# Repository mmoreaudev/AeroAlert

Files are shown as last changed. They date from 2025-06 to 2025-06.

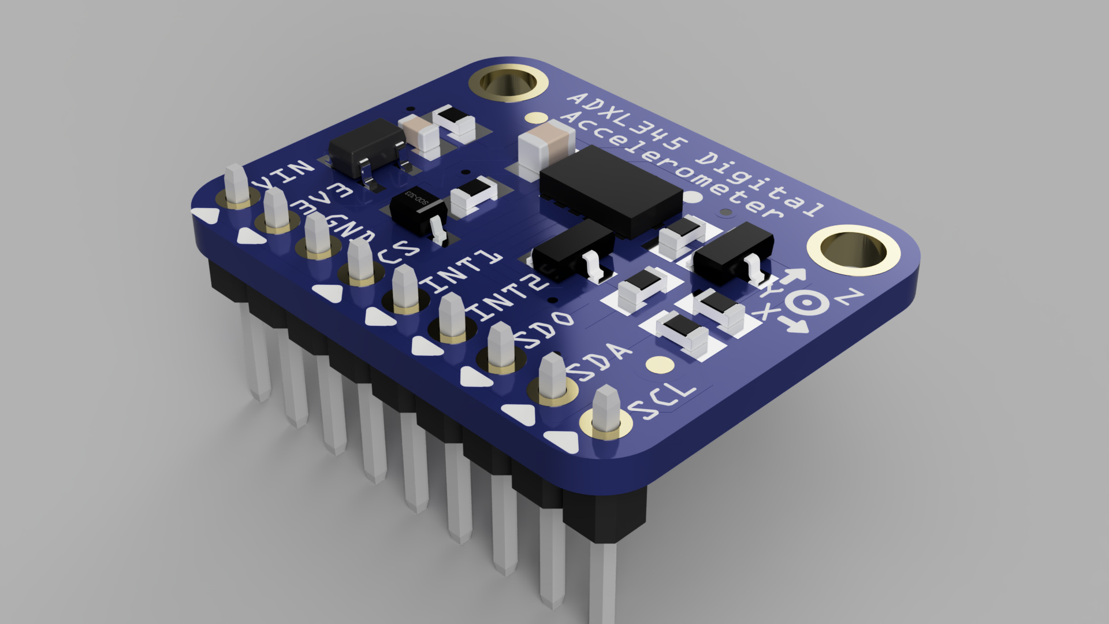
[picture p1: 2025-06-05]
Carte PCB/adxl345-digital-accelerometer-adafuit-breakout-board-1.snapshot.1/Render 2.jpg

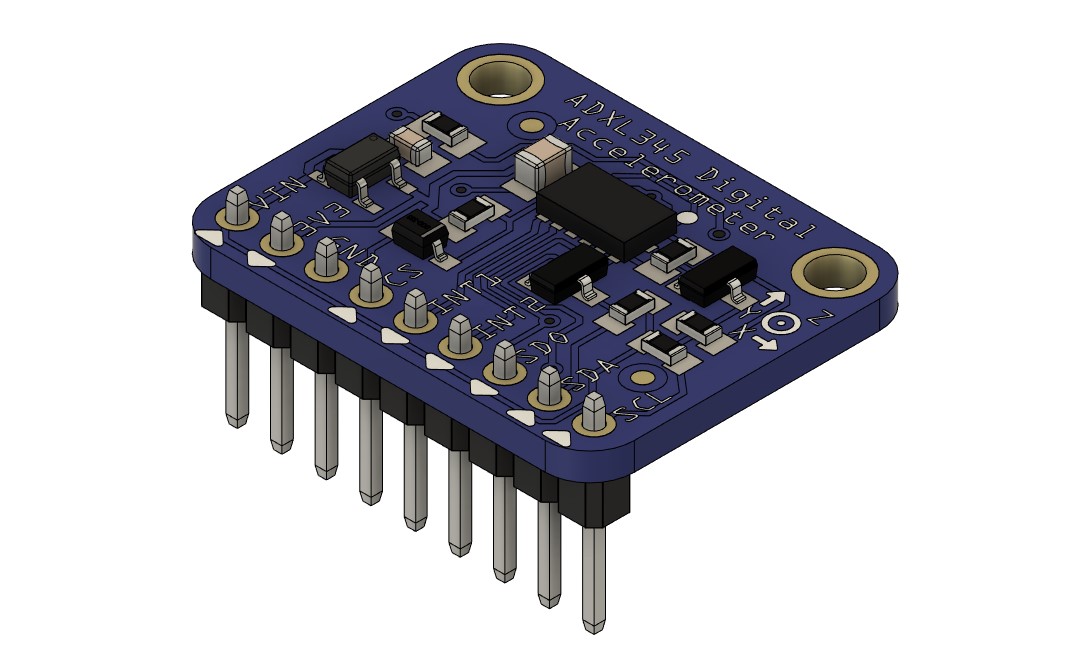
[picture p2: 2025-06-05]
Carte PCB/adxl345-digital-accelerometer-adafuit-breakout-board-1.snapshot.1/ADXL345 Digital Accelerometer.jpg

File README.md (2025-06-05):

# 🌤️ AeroAlert

**AeroAlert** is a lightweight, reusable, and cost-effective meteorological probe system designed to study **meteorological epiphenomena** using miniaturized sensors deployed via rockets. Our goal is to improve understanding and forecasting of high-risk weather events by collecting simultaneous atmospheric data across multiple points within a small geographical area.

---

## 🚀 Project Overview

The AeroAlert system works as follows:

1. **Launch**: A compact rocket is launched into the atmosphere.
2. **Deployment**: Upon reaching maximum altitude, a parachute is deployed.
3. **Data Collection**: While descending, the onboard sensors collect meteorological data.
4. **Storage & Visualization**: Collected data is stored and later visualized using a dedicated Human-Machine Interface (HMI).

---

## 🎯 Purpose

The core objective of AeroAlert is to **study meteorological epiphenomena**—those rare or secondary weather-related events that are often difficult to capture using conventional equipment. By deploying multiple inexpensive probes simultaneously across a small region, we can:

- Collect high-resolution atmospheric data
- Analyze localized phenomena
- Improve early detection and forecasting of extreme weather conditions

---

## 🧰 Technologies Used

- 🛰️ **Embedded sensors** for atmospheric data (e.g., temperature, humidity, pressure)
- 💻 **Microcontroller (e.g., Arduino, ESP32)** for data acquisition and storage
- 🪂 **Mechanical parachute deployment system**
- 📈 **HMI (Human-Machine Interface)** for data visualization
- 🚀 **Model rocket system** for deployment
- 🔋 **Battery-powered modules** for portability and reusability

---

## 🛠️ Installation & Setup

> *Note: Hardware setup and code repository coming soon*

### Prerequisites

- Microcontroller development environment (e.g., MICROCHIP)
- Sensor modules (temperature, pressure, humidity, etc.)
- Model rocket and deployment hardware
- Local or web-based interface for HMI

### Clone the Repository

```bash
git clone https://github.com/your-username/aeroalert.git
cd aeroalert
```

## 📊 Data & Visualization
All collected meteorological data (such as temperature, pressure, and humidity at various altitudes) is stored in onboard memory and can be exported in CSV/JSON format. The HMI displays this data through:

- Interactive graphs 📉
- Real-time metrics 📡
- Historical logs 🗂️
- ♻️ Reusability & Portability

## AeroAlert is designed with:

- 🔋 Long battery life
- 🪶 Lightweight components
- 🔄 Modular structure for easy reconfiguration and redeployment
- 🤝 Contributing

Contributions are welcome! Feel free to fork the repository and submit a pull request. Whether you're into electronics, data science, or rocket science — we’d love your help! 🛠️

1. Fork the project
2. Create your feature branch (git checkout -b feature/AmazingFeature)
3. Commit your changes (git commit -m 'Add some AmazingFeature')
4. Push to the branch (git push origin feature/AmazingFeature)
5. Open a Pull Request

### 📄 License
This project is licensed under the MIT License.

See the LICENSE file for more details.

## 🌐 Acknowledgments
Translations by DeepL
Open-source community for sensor integration support
Educators and meteorologists providing guidance on atmospheric studies

### AeroAlert – Because understanding the sky helps us protect the Earth. ☁️🌎

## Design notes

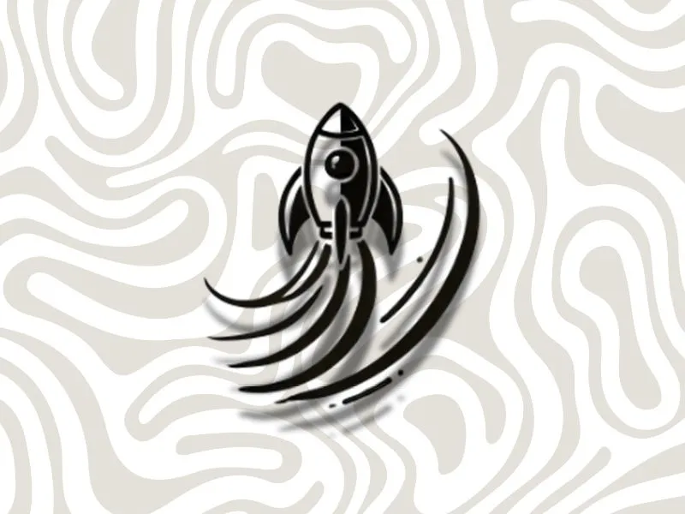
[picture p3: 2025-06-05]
Baniere.webp

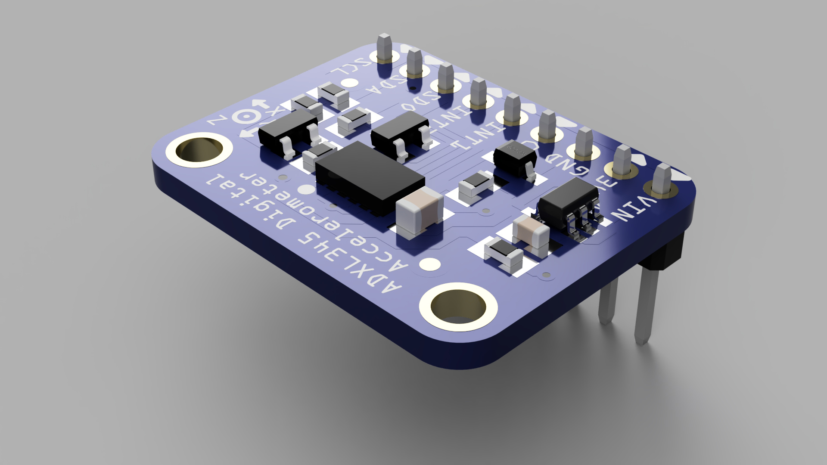
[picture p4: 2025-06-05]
Carte PCB/adxl345-digital-accelerometer-adafuit-breakout-board-1.snapshot.1/Render 1.jpg

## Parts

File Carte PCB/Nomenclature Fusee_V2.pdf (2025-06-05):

MATAILET

## Nomenclature pour Fusee_V2

Titre projet | Fusee_V2
Auteur | | J CESBRON

### Numéro document Révision

Projet créé | lundi 24 mars 2025

### Dernière modification projet jeudi 27 mars 2025 Total éléments du projet 50

8 Capacitors
Quantité Références | Valeur | Fournisseur | CODE
STOCK
| | | | unité coût
5 | C1,C3,C8-C9,C12 | 100nF
1 | C2 | 10uF | FARNELL | 0,348
1 | C7 | 47u
1 | C10 | 100nF | FARNELL | 0,114
Sous-total:
15 Résistances
Quantité Références | Valeur | Fournisseur | CODE
STOCK
| | | | unité coût
3 | R1,R7,R15 | 10k
1 | R2 | 10k | Atlantique composants | 0,0836
1 | R5 | 14.7k | Atlantique composants | 0,0836
4 | R6,R8,R18-R19 | 1.5k
2 | R14,R16 | 1k
1 | R17 | 100k
1 | R21 | 4.7k | FARNELL | 0,023
1 | R22 | 470 | FARNELL | 0,025
1 | R39 | 10
Sous-total:
3 Diodes
Quantité Références | Valeur | Fournisseur | CODE
STOCK
| | | | unité coût
1 | D3 | 1N4004 | | 0,0153
1 | D4 | LED-R-AT2
1 | D8 | LED-R-AT1
Sous-total:
24 Divers
Quantité Références | Valeur | Fournisseur | CODE
STOCK
| | | | unité coût
1 | +3.3V | LED-R-Alim-3.3V
1 | ALM BAT | LED-R-ALM BAT
3 | AT-HC05,GO,RAZ-HC05 | SW-PUSH-CMS
1 | J1 | ACCU
1 | J4 | CONN-SIL6
1 | J6 | Connecteur JACK ALIM
1 | J10 | Inter ON/OFF
2 | LEDALIM/OK,LED-BT | BTWM3 | LEXTRONIC | 0,5
1 | ON/OFF | Interrupteur
1 | PICKIT3 | CON-PICKIT
2 | RX-HC05,TX-HC05 | PIN

1 | SERVO | CONN-SIL3
1 | U1 | NCP1117
1 | U2 | PIC18F25K80
1 | U3 | ADXL345
1 | U4 | BMP280
1 | U5 | HC05_SERIAL_BLUETOOTH
1 | U4-TE583 | TE583
2 | USB-RS232-HC05,USB-RS232- IHM

Sous-total:

Totaux:

lundi 5 mai 2025 13:39:03

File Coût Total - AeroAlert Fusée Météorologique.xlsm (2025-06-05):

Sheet: Coût de production
AeroAlert - Fusée Météorologique |  |  |  |  |  |  |  |  |  | 0
 |  |  |  | NB. DE FUSÉE(S) | 1
 | COUT/FUSÉE HT | 49.17 € |  | COUT TOTAL HT | 49.17 €
 | TVA 20% | 20% |  | TVA 20% | J
 | COUT/FUSÉE TTC | 59.01 € |  | COUT TOTAL TTC | 59.01 €
#VALUE! | Désignation | Référence schéma | Valeur | Fournisseur | Référence fournisseur | Quantité | Prix unitaire HT | Prix unitaire TTC | TOTAL PARTIEL TTC
Composants | Condensateures | C1,C3,C8-C10,C12 | 100nF | Farnell | 197543 | 6 | 0.598 € | 0.718 € | 4.306 €
 | Condensateures | C2 | 10µF | Farnell | 2112921 | 1 | 0.450 € | 0.540 € | 0.540 €
 | Condensateures | C7 | 47µF | Farnell | 1457429 | 1 | 0.216 € | 0.259 € | 0.259 €
 | Résistances | R1-R2,R7,R15 | 10k | Farnell | 9240640 | 4 | 0.021 € | 0.025 € | 0.098 €
 | Résistances | R5 | 14,7k | Farnell | 2307401 | 1 | 0.039 € | 0.047 € | 0.047 €
 | Résistances | R6,R8,R18-R19 | 1,5k | Farnell | 2331729 | 4 | 0.006 € | 0.007 € | 0.027 €
 | Résistances | R14,R16 | 1k | Farnell | 1717745 | 2 | 0.206 € | 0.247 € | 0.494 €
 | Résistances | R17 | 100k | Farnell | 9233628 | 1 | 0.022 € | 0.026 € | 0.026 €
 | Résistances | R21 | 4,7k | Farnell | 9240608 | 1 | 0.022 € | 0.027 € | 0.027 €
 | Résistances | R22 | 470 | Farnell | 9232729 | 1 | 0.006 € | 0.007 € | 0.007 €
 | Résistances | R39 | 10 | Farnell | 9232524 | 1 | 0.008 € | 0.009 € | 0.009 €
 | Diodes | D3 | 1N4004 | Farnell | 4245043 | 1 | 0.100 € | 0.120 € | 0.120 €
 | LED | D4,D8,+3.3V,ALM BAT | 2.2V, 10mA | Atlentique Composants | DL3RF | 4 | 0.550 € | 0.660 € | 2.640 €
 | Boutons poussoirs | AT-HC05,GO,RAZ-HC05,BP GO | 6x6x4.3 | Aliexpress | Lien (https://fr.aliexpress.com/item/1005004254514071.html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) | 4 | 0.103 € | 0.124 € | 0.494 €
 | Point Test | TX-HC05, RX-HC05 | - | Atlentique Composants | SCCIM2 | 2 | 0.056 € | 0.067 € | 0.135 €
 | Connecteur | USB-RS232-IHM | - | Atlentique Composants | K2B40FC | 1 | 0.167 € | 0.200 € | 0.200 €
 | Connecteur | USB-RS232-HC05 | - | Atlentique Composants | K2B40F | 1 | 0.167 € | 0.200 € | 0.200 €
 | JACK ALIM | J6 | 12V DC | Farnell | FC68148S | 1 | 1.86 € | 2.232 € | 2.232 €
 | Connecteur PCB | J4 | - | LEXTRONIC | BTWM3 | 1 | 0.500 € | 0.600 € | 0.600 €
 | ACCU | J1 | - | LEXTRONIC | BTWM3 | 1 | 0.500 € | 0.600 € | 0.600 €
 | Inter ON/OFF | J10 | - | LEXTRONIC | BTWM4 | 1 | 0.500 € | 0.600 € | 0.600 €
 | Connecteur PICKIT | PICKIT3 | - | Atlentique Composants | K2B40 | 1 | 1.11 € | 1.336 € | 1.336 €
 | Connecteur PCB | LED ALIM/OK, LED-BT | - | LEXTRONIC | BTWM3 | 2 | 0.500 € | 0.600 € | 1.200 €
 | Regulateur de tension | U1 | - | RS | NCP1117 | 1 | 0.227 € | 0.275 € | 0.275 €
 | Microcontroleur | U2 | - | Digikey | PIC18F25K80 | 1 | 3.030 € | 3.636 € | 3.636 €
Modules | Accelerometre | U3 | - | Aliexpress | ADXL345 | 1 | 1.325 € | 1.590 € | 1.590 €
 | Capteur pression/temperature | U4 | - | Aliexpress | BMP280 | 1 | 1.208 € | 1.450 € | 1.450 €
 | Module Bluetooth | U5 | - | Aliexpress | HC-05 | 1 | 1.483 € | 1.780 € | 1.780 €
 | Servo moteur | SERVO | - | Aliexpress | MG90S | 1 | 1.225 € | 1.470 € | 1.470 €
 | chargeur de batterie | U4-TE583 | - | Aliexpress | TP4056 | 1 | 0.245 € | 0.294 € | 0.294 €
 | Désignation | Taille (Rayon en mm) | Epaisseur | Fournisseur | Frais de livraison | Quantité | Prix unitaire HT | Prix unitaire TTC | TOTAL PARTIEL TTC
Fabrication PCB | Circuit Imprimé | 45 | 1.4 | JLC PCB | 22 € | 1 | 4.167 € | 5.000 € | 27.000 €
 | Désignation | Taille | Poids | Fournisseur | Référence fournisseur | Quantité | Prix unitaire bobine HT | Prix unitaire bobine TTC | TOTAL PARTIEL TTC
Plastique | Corps bleu | - | 59.50 g | ESUN | PLA + | 1 | 17.49 € | 20.99 € | 1.25 €
 | Coiffe | - | 80.40 g | ESUN | PLA + | 1 | 17.49 € | 20.99 € | 1.69 €
 | Raccord | - | 8.60 g | ESUN | PLA + | 1 | 17.49 € | 20.99 € | 0.18 €
 | Bouteille | - | 34.10 g | - | Eau Minérale Naturelle Gazeuse PERRIER | 1 | 0.57 € | 0.68 € | 0.68 €
 | Désignation | Taille | Type | Fournisseur | Référence fournisseur | Quantité | Prix unitaire HT | Prix unitaire TTC | TOTAL PARTIEL TTC
Assemblage | Vis ronde a fente | M2x20mm | Inox | Atlantique Composants | SVM220 | 4 | 0.131 € | 0.158 € | 0.631 €
 | Boulon | M2 | Inox | Atlantique Composants | SVME2 | 2 | 0.111 € | 0.133 € | 0.267 €
 | Rondelle | M2 | Inox | Atlantique Composants | SVMRP3 | 8 | 0.023 € | 0.027 € | 0.219 €
 | Tige fileté | - | - | AéroAlert | - | 4 | 0.080 € | 0.100 € | 0.400 €

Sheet: Consommation
Calcul de l'autonomie
Composants | Consommation typique (mA) | Consommation sur 10 minutes
PIC18F25K80 | 15 mA | 2.5 mAh
HC-05 (Bluetooth) | 40 mA | 6.7 mAh
Servo MG90S | 300 mA (en activité) | 0.167 mAh
ADXL345 (accéléro) | 0.04 mA | 0.007 mAh
BMP280 (baromètre) | 0.72 mA | 0.12 mAh
LEDs x4 | 80 mA | 13.3 mAh
Total estimé | 435.76 mA | 27.6 mAh
Nombre de cycle possible sur 1000 mAh |  | 36.23 cycles

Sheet: Caractéristique de tranfert
Caractéristiques de transfert
Température (°C) | Valeur brute (LSB) | Pression (hPa) | Valeur brute (LSB)
-40 | -4000 | 300 | 30000
-20 | -2000 | 500 | 50000
0 | 0 | 700 | 70000
20 | 2000 | 900 | 90000
25 | 2500 | 1013 | 101300
30 | 3000 | 1050 | 105000
40 | 4000 | 1100 | 110000
60 | 6000
85 | 8500
 | LSBT = T(°C) x 100 |  | LSBP = P(hPa) x 100
 |  |  | Altitude (m) | Température (°C) | Pression (hPa)
 |  |  | 0 | 22 | 1015
 |  |  | 100 | 21 | 1013
 |  |  | 200 | 20 | 1011
 |  |  | 300 | 19 | 1009
 |  |  | 400 | 18 | 1007
 |  |  | 500 | 17 | 1700
 |  |  | 600 | 16 | 1003
 |  |  | 700 | 15 | 1001
 |  |  | 800 | 14 | 999
 |  |  | 900 | 13 | 997
 |  |  |  | Taux décroissance T (°C/km) | 10
 |  |  |  | Pression moyenne (hPa) | 1075.5
 |  |  |  | Stabilité (lapse rate - 9.8) | 0.2
 |  |  |  | Estimation météo | Instable (Risque orage/pluie)

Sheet: Comportements des capteurs
Modèles de comportement des capteurs
BMP280 |  |  | HC-05
Paramètre | Température | Pression | Paramètre | Valeur
Grandeur mesurée | Température (°C) | Pression (hPa) | Fonction | Communication série sans fil (UART)
Sortie (valeur brute) | Valeur numérique (LSB, sur 16 ou 20 bits) | Valeur numérique (LSB, sur 20 bits) | Type de données | Transmet les valeurs mesurées
Modèle mathématique | LSB = Température × 100 | LSB = Pression × 100 | Modèle de comportement | Pas un capteur : pas de relation physique ↔ valeur
Plage de mesure | -40 °C à +85 °C | 300 hPa à 1100 hPa | Vitesse | 9600 bps (par défaut)
Résolution | ~0,01 °C | ~0,16 hPa | Portée | Jusqu’à 10 m
Type de sortie | Numérique (I2C ou SPI) | Numérique (I2C ou SPI) | Alimentation | 3,3 V / 5 V

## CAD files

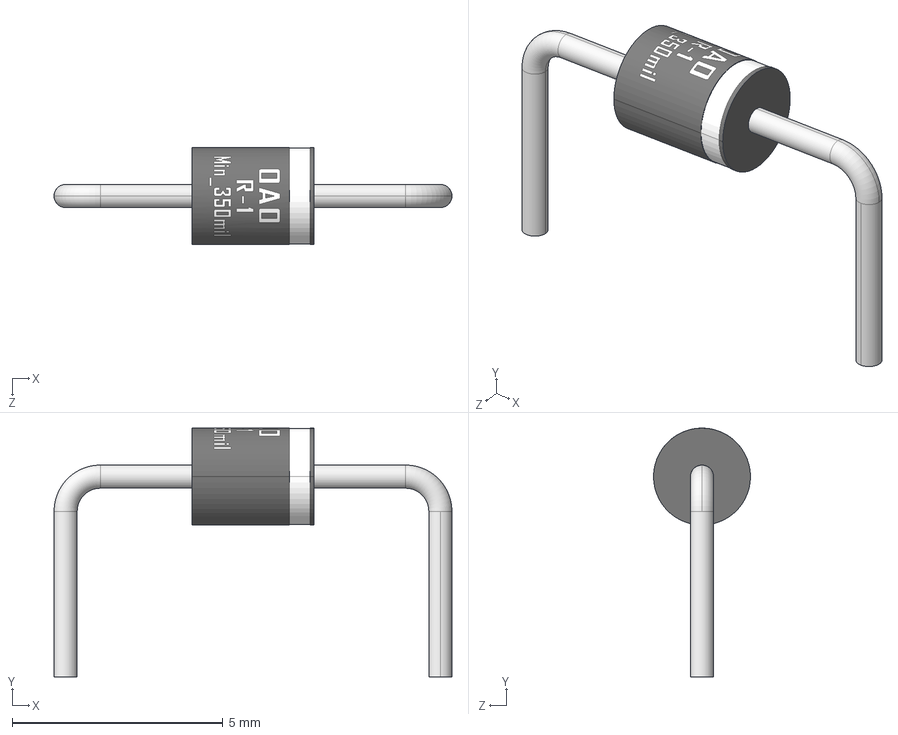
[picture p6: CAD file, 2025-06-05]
Carte PCB/R-1_Min_350mil_rev1.0.STEP
9.44 x 5.90 x 2.30 mm

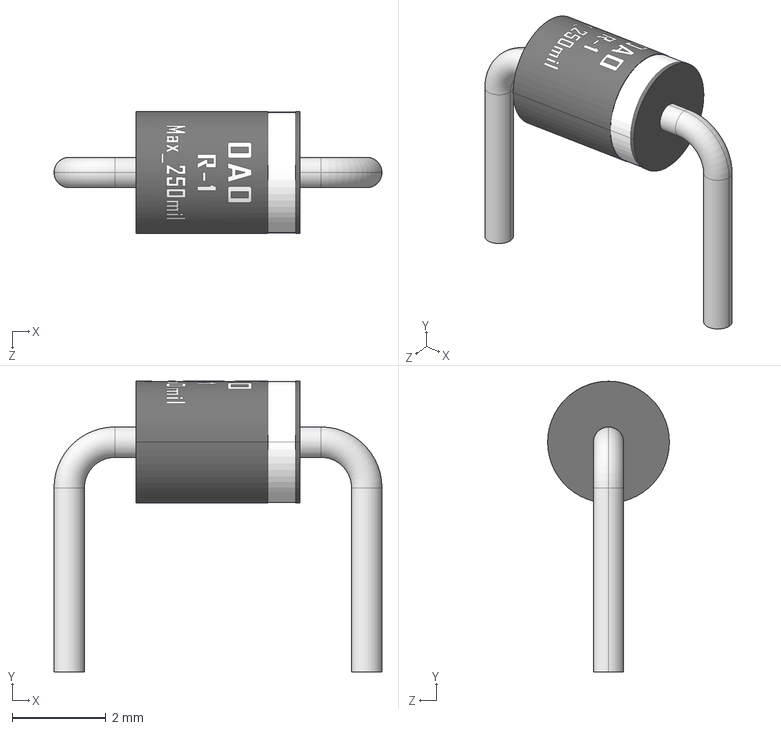
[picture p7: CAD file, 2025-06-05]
Carte PCB/R-1_Max_250mil_rev1.0.STEP
7.00 x 6.20 x 2.60 mm
